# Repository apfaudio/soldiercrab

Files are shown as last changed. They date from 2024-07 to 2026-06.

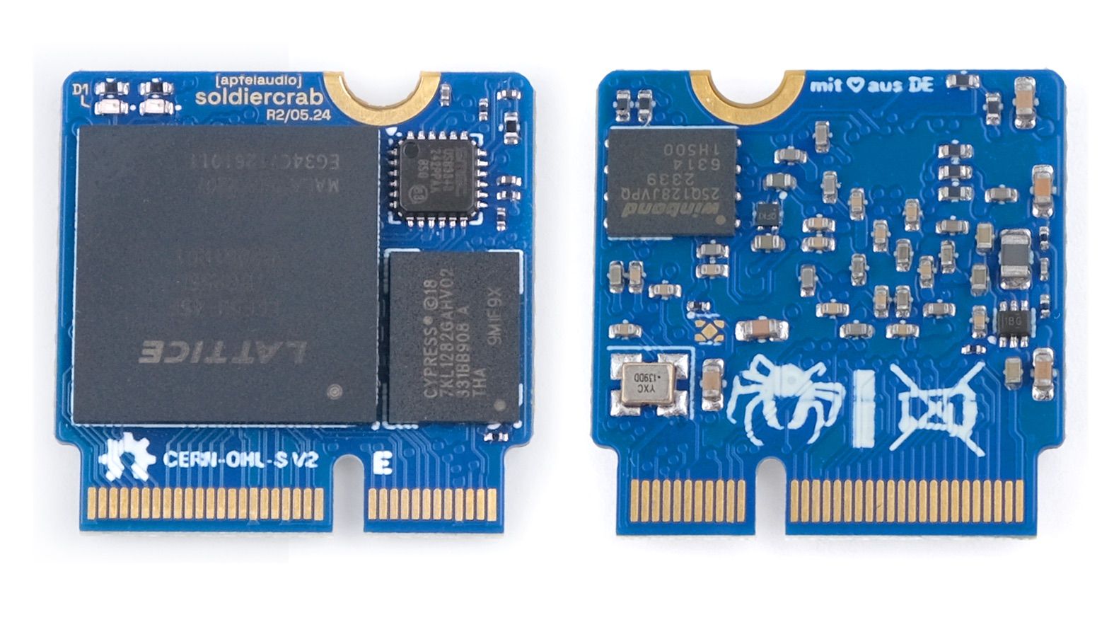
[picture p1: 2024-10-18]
img/soldiercrab-r2.jpg

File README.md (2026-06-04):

# SoldierCrab

[**SoldierCrab**](https://en.wikipedia.org/wiki/Mictyris_longicarpus) is an embeddable FPGA SoM (System-on-Module) designed for use in high-speed audio and USB applications.
It is the brain of [tiliqua](https://github.com/apfaudio/tiliqua) and other [apf.audio products](https://apf.audio/), and looks like this:



A high-level block diagram:



**SoldierCrab** has the following core features:
- **ECP5 FPGA**: -25K or -45K variant, caBGA256 (note: SERDES/PCIe not available in this package!)
- **HyperRAM / oSPI-RAM**: tested up to 3.2Gbit/sec, or 3.8Gbit/sec with timing violations :)
- **USB2 HS PHY**: 480Mbit/sec, with exposed ID, it can be used in device or host mode
- **1V1 / 1V8 / 2V5 regulators onboard**, 3V3 is all that's needed
- **PROGRAMN internally looped back** for multibooting bitstreams / internal bootloader
- 2 indicator LEDs on the PCBA
- 48MHz master clock
- Card edge is basically: **47 exposed general purpose pins + 4-pin JTAG + USB2**
- 22mmx22mm board size with M.2 E-key card edge (see 'Physical Compatibility' below)

## Hardware Revisions

**There are currently 2 revisions of SoldierCrab in the wild.**
- **R2.0**: LFE5U-45 with 7KL1282GAHY02 (3.3V HyperRAM, tested up to 200MB/sec)
- **R3.0**: LFE5U-25 with APS256XXN-OBR (1.8V oSPI-RAM, tested up to 400MB/sec)

PDF schematics for both can be found in the `schematics-pdf` folder.

## Footprint / Physical Compatibility

**The SoldierCrab is 22mmx22mm (+/- 0.3mm) with an M.2 E-key connector and offset mounting hole**. The mounting hole is offset such that this board is physically compatible with the SparkFun MicroMod format, however we **do not claim electrical compatibility with it** (even though this SoM will work with some MicroMod boards, the JTAG and I2C connections are in the wrong place for us to claim complete compatibility - this is intentional design choice to save routing space whilst trying to remain close to some kind of SoM standard).

On my carrier boards, as a connector I am using a [TE Connectivity 2199230-4](https://www.lcsc.com/product-detail/Edgeboard-Connectors_TE-Connectivity-2199230-4_C2977809.html).

A nice resource for [designing appropriate carrier boards can be found here](https://learn.sparkfun.com/tutorials/designing-with-micromod/how-to-design-a-micromod-carrier-board). However, keep the above in mind, make sure your JTAG and I2C pinouts match the SoldierCrab ones.

## Pinout

Aside from in the schematic, you can find a (tested!) version of the SoM pinout in `amaranth-boards` format [here in the Tiliqua repository](https://github.com/apfaudio/tiliqua/blob/e4d43d70f0be8f8c47809bad94cfb414b5939a86/gateware/src/tiliqua/tiliqua_platform.py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).

#### R3.0 Complementary Pairs

These pins on the M.2 connector are best for differential outputs (e.g. DVI).

```
6 are adjacent on the same side:
[(13, 15), (20, 22), (52, 54), (58, 60), (62, 64), (68, 70)]
2 are almost adjacent (1 pin gap) on the same side:
[(55, 59), (67, 71)]
10 not adjacent (>1pin gap or different sides):
[(6, 17), (11, 19), (34, 35), (38, 41), (37, 43), (40, 47), (46, 57),, (63, 69)]
```

## Where do I get one?

Pre-assembled and tested SoldierCrabs are available on [Crowd Supply](https://www.crowdsupply.com/apfaudio/tiliqua) (ships from US) or by [emailing me](https://apf.audio/impressum/) (ships from EU).

I've also published an open-hardware [carrier board called 'sandflat'](https://github.com/apfaudio/sandflat) which is a cheaper (and less feature-rich) alternative to Tiliqua, if you're just wanting to test out SoldierCrab in your own domain.

# Bootloader

In theory, this SoM could bootload itself over the ULPI USB2 PHY, however I haven't started on this yet. This means a carrier board must expose the JTAG pins for an external programmer (check the schematic).

## Builds on the following (awesome) open-hardware projects
- The [Cynthion](https://github.com/greatscottgadgets/cynthion-hardware) project from Great Scott Gadgets.
- The [OrangeCrab](https://github.com/orangecrab-fpga/orangecrab-hardware) project from Greg Davill.
- Inspired by [Sparkfun Micromod](https://www.sparkfun.com/micromod), even though we are not 100% compatible with it.

# License

**Copyright (C) 2024 S. Holzapfel**

The files in this project are largely covered under the CERN Open-Hardware License V2 CERN-OHL-S, mirrored in the LICENSE text in this repository. This LICENSE and copyright notice do NOT apply to imported artifacts in this repository (i.e datasheets, third-party 3D models, symbols or footprints), or to dependencies released under a different (but compatible) open-source license.

# Derivative works

As an addendum to the above license: if you create or manufacture your own derivative hardware, the name `apf.audio`, the names of any `apf.audio` products and the names of the authors, are *not to be used in derivative hardware or marketing materials*, except where obligated for attribution and for retaining the above copyright notice.

For example, your adaptation of "apf.audio SoldierCrab" could be called "Sandy Modular - Clawcruncher".

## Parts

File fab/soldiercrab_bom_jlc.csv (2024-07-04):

Comment | Designator | Footprint | LCSC Part #
2.2uF | C1,C2,C3,C4,C23 | C_0603_1608Metric | C23630
1uF | C5,C19,C21,C8,C13,C16,C17,C18,C22,C79,C80,C81,C82,C83 | C_0402_1005Metric | C52923
10uF | C6,C28,C29 | C_0402_1005Metric | C105884
0.1uF | C10,C35,C31,C32,C65,C7,C9,C11,C12,C14,C15,C24,C26,C33 | C_0402_1005Metric | C1525
4.7uF | C20,C27 | C_0402_1005Metric | C326586
10pF | C25 | C_0201_0603Metric | C526922
1uF | C34,C36,C37 | C_0201_0603Metric | C87143
LED 0402 RED | D1,D2 | LED_0402_1005Metric | C965790
ECP5-BGA256 | IC1 | lattice_cabga256 | C1521614
2.2uH | L1 | L_0805_2012Metric | C216156
10k | R1 | R_0201_0603Metric | C106225
100k | R2 | R_0201_0603Metric | C106224
120k | R3 | R_0201_0603Metric | C274344
2.2k | R5 | R_0402_1005Metric | C25879
5.1k | R6,R13,R109 | R_0402_1005Metric | C25905
8.06k | R7 | R_0201_0603Metric | C516470
20K | R8 | R_0402_1005Metric | C93942
27R | R9,R10 | R_0201_0603Metric | C270320
330 | R11,R12,R14,R15 | R_0402_1005Metric | C25104
330 | R108 | R_0201_0603Metric | C274872
10k | R110 | R_0402_1005Metric | C25744
TLV62569ADRLR | U1 | SOT-563 | C398367
NCP115-2.5 | U2 | Texas_X2SON-4_1x1mm_P0.65mm | C892044
NCP115-1.8 | U4 | Texas_X2SON-4_1x1mm_P0.65mm | C603501
USB3343 | U3 | QFN-24-1EP_4x4mm_P0.5mm_EP2.6x2.6mm | C633347
W25Q128JVP | U7 | WSON-8-1EP_6x5mm_P1.27mm_EP3.4x4mm | C190862
HyperRAM | U10 | BGA-24_5x5_6.0x8.0mm | C5448342
Osc48MHz | Y1 | Crystal_SMD_3225-4Pin_3.2x2.5mm | C669070

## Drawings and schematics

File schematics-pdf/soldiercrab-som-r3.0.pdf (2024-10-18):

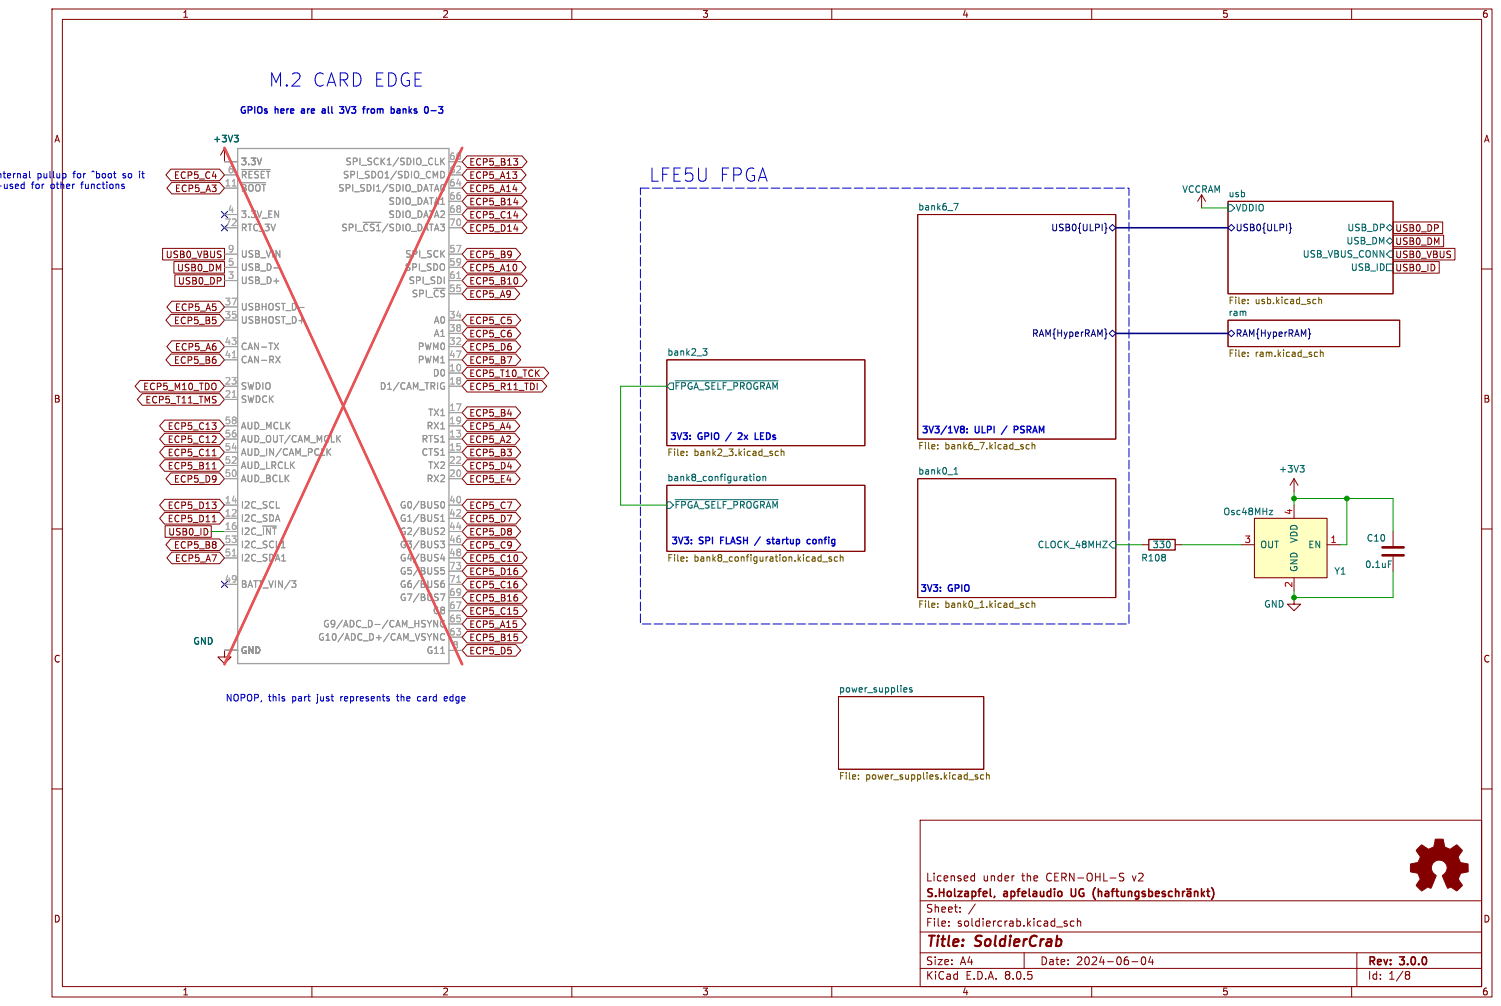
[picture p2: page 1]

3V3: GPIO / 2x LEDs GPIOs here are all 3V3 from banks 0-3 M.2 CARD EDGE

USB0{ULPI} usb File: usb.kicad_sch RAM{HyperRAM}

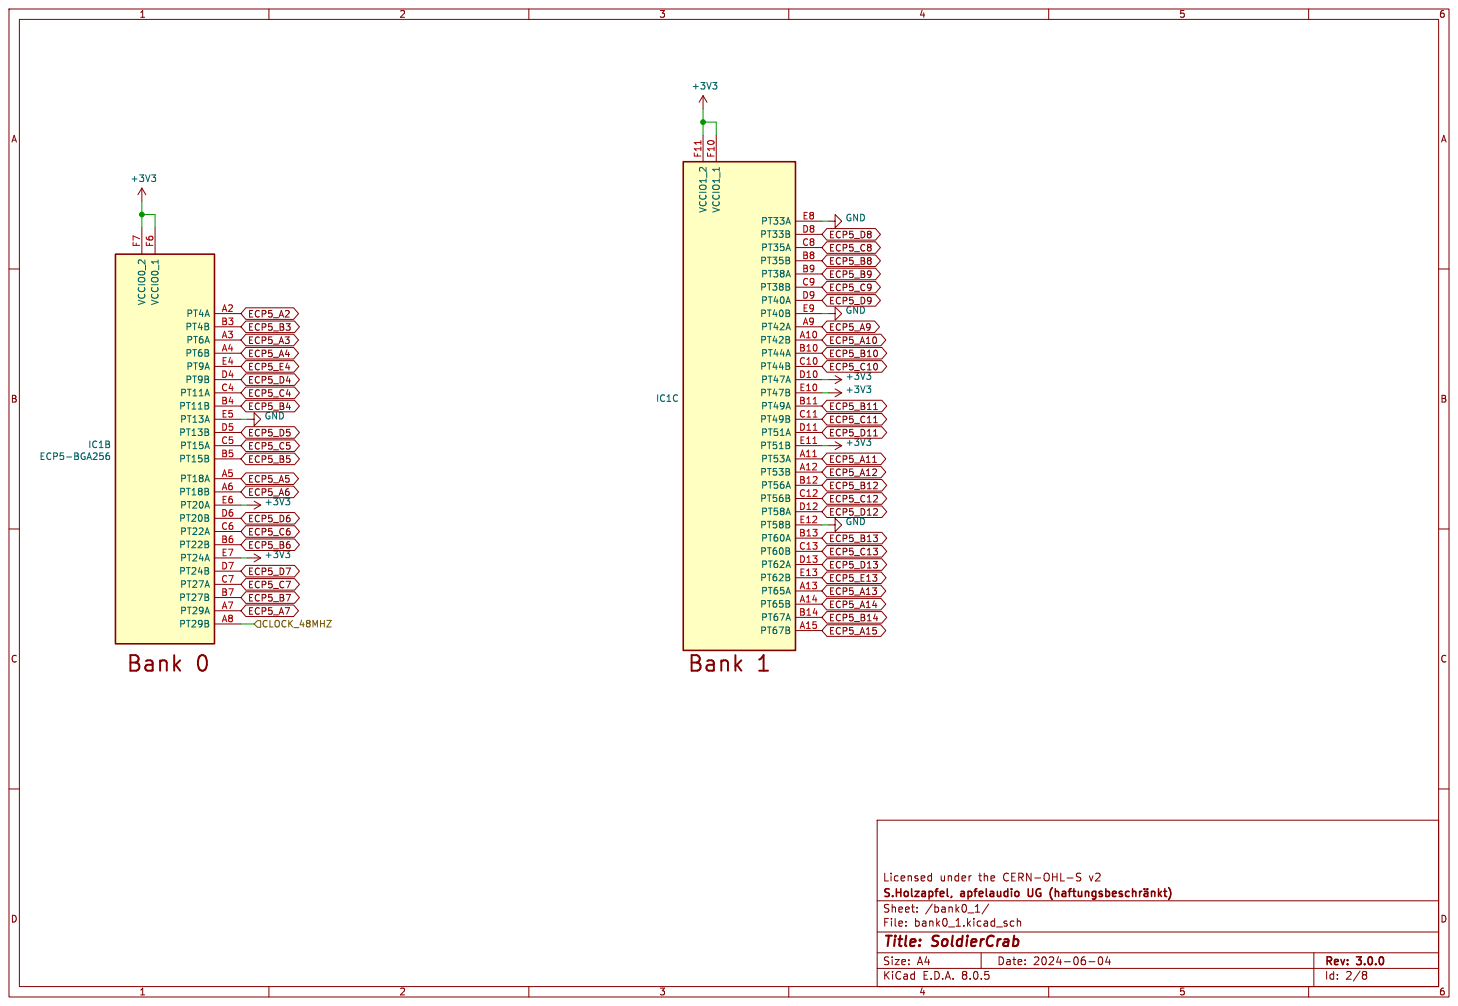
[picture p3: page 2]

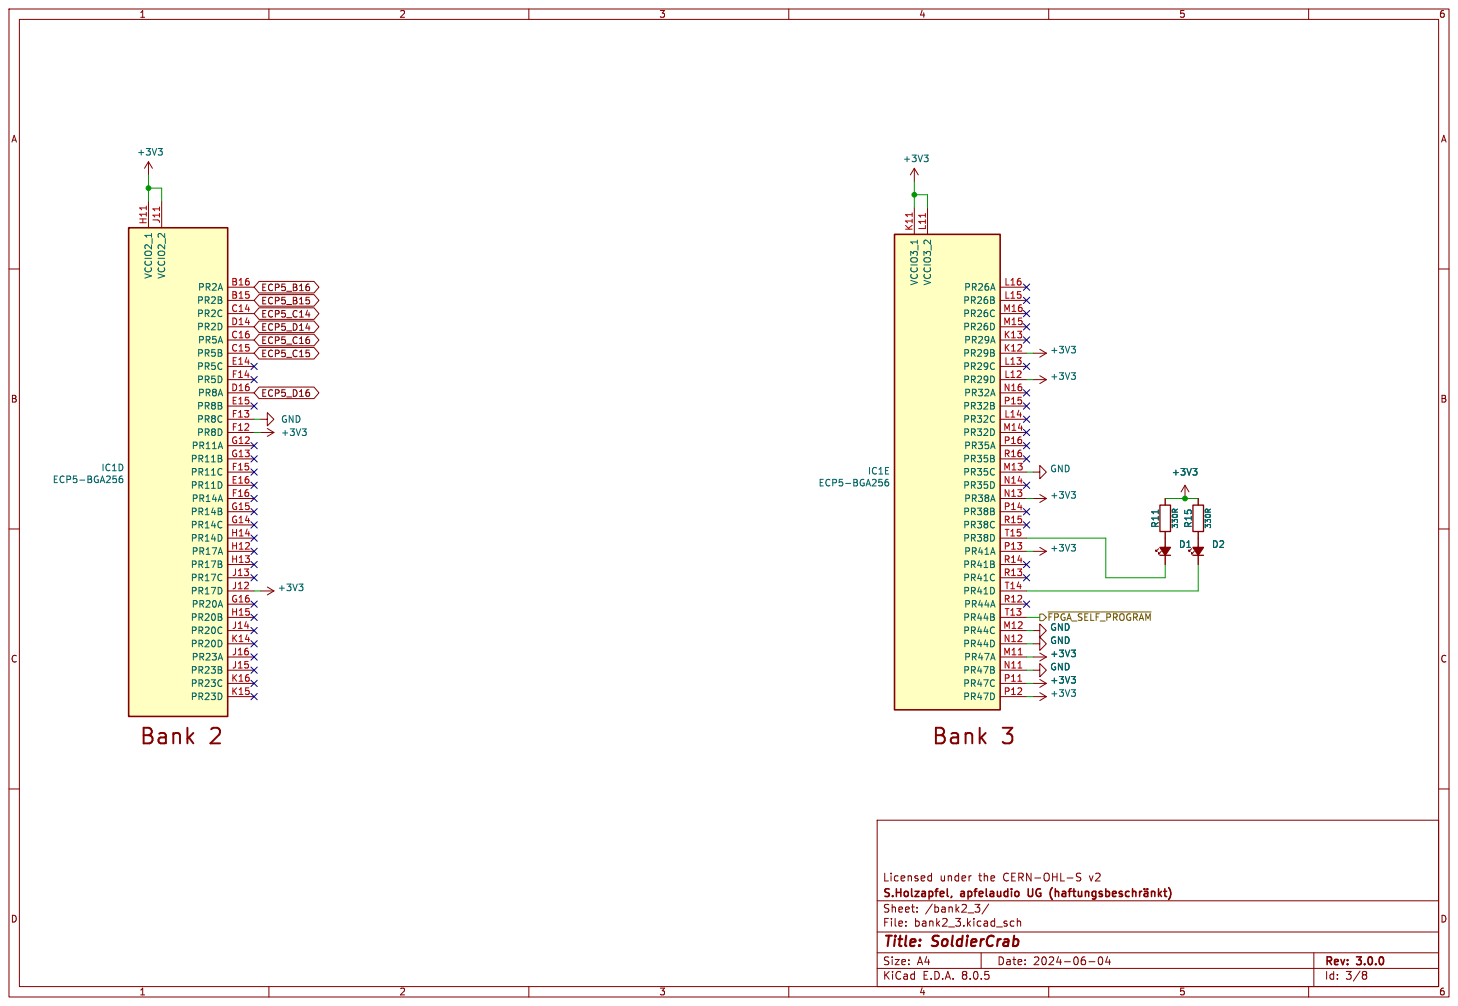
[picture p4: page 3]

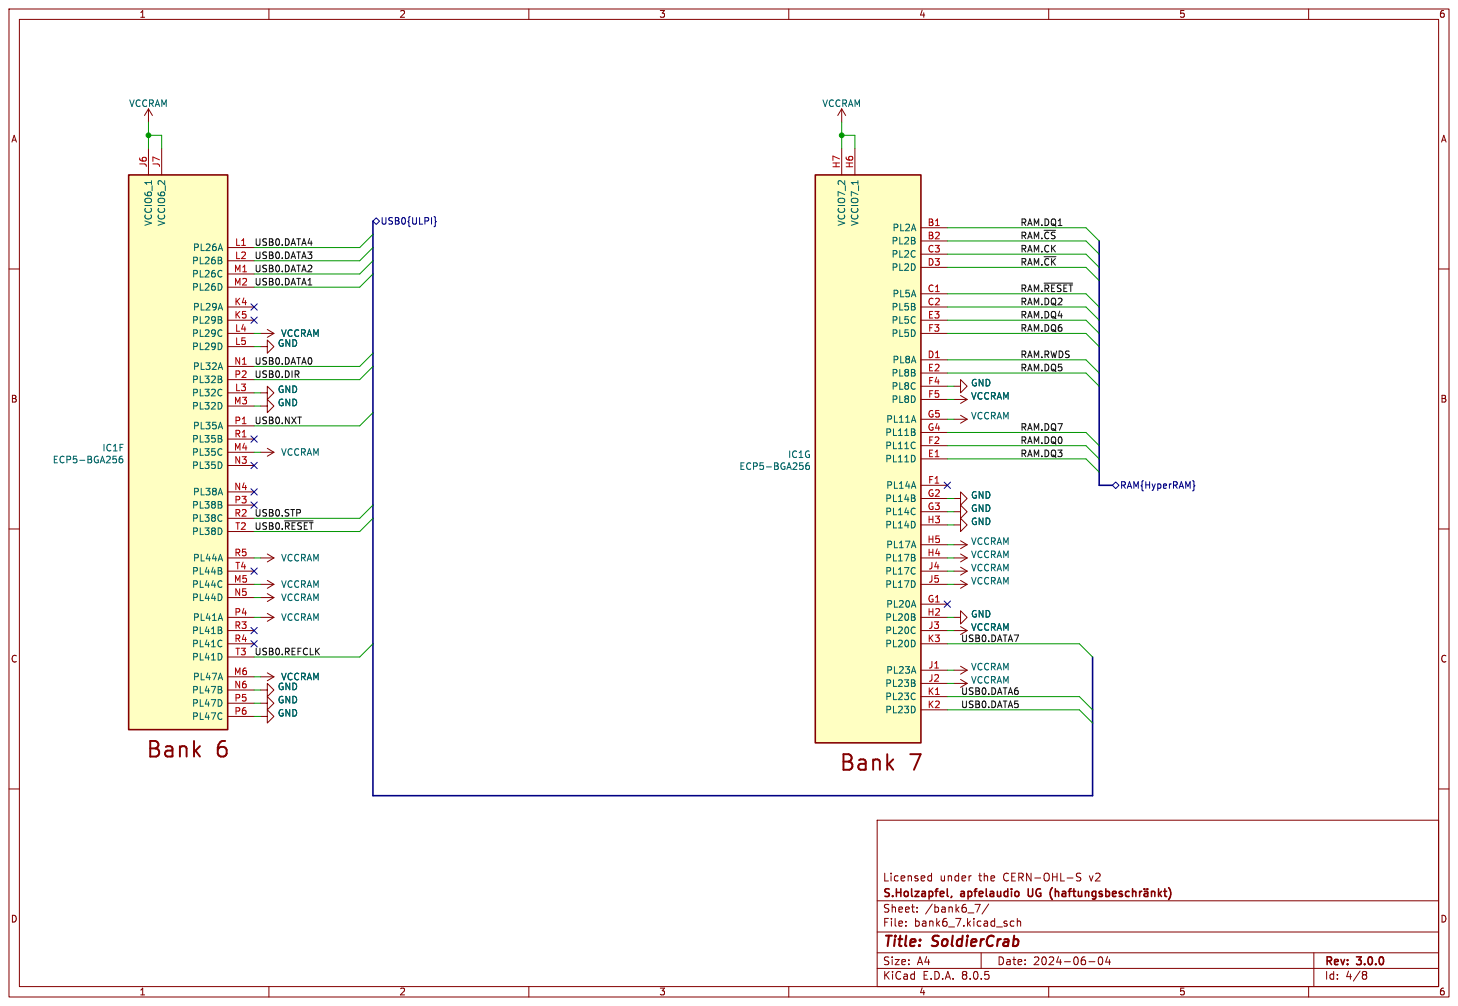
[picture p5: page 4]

RAM{HyperRAM} RAM.CK RAM.~{CK}

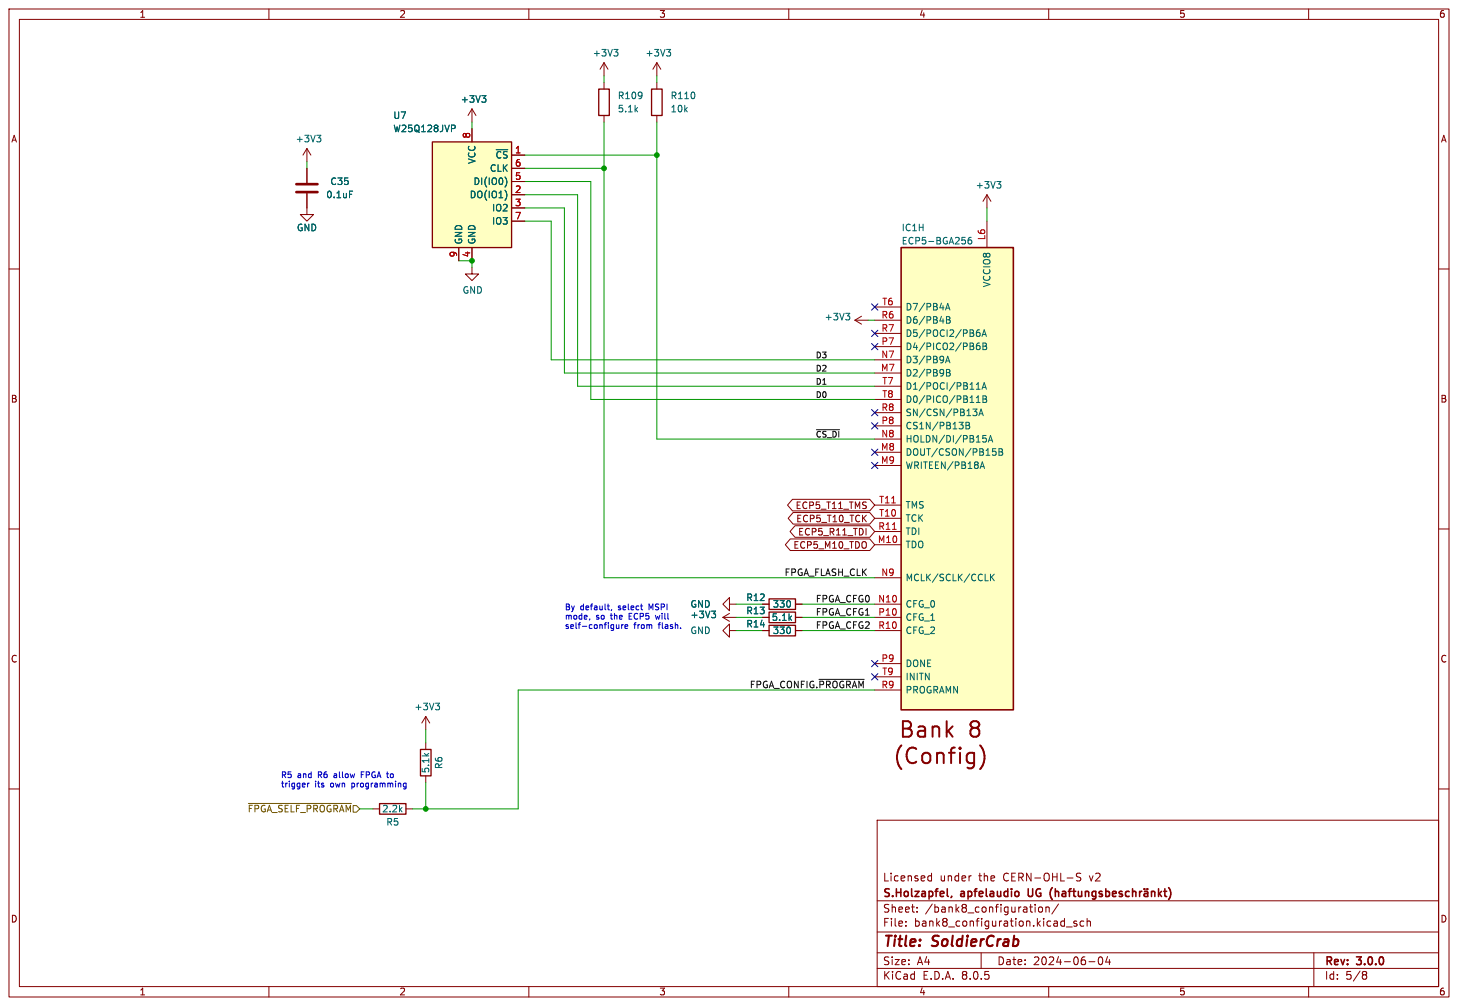
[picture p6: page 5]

~{CS_DI} D1 R5 and R6 allow FPGA to

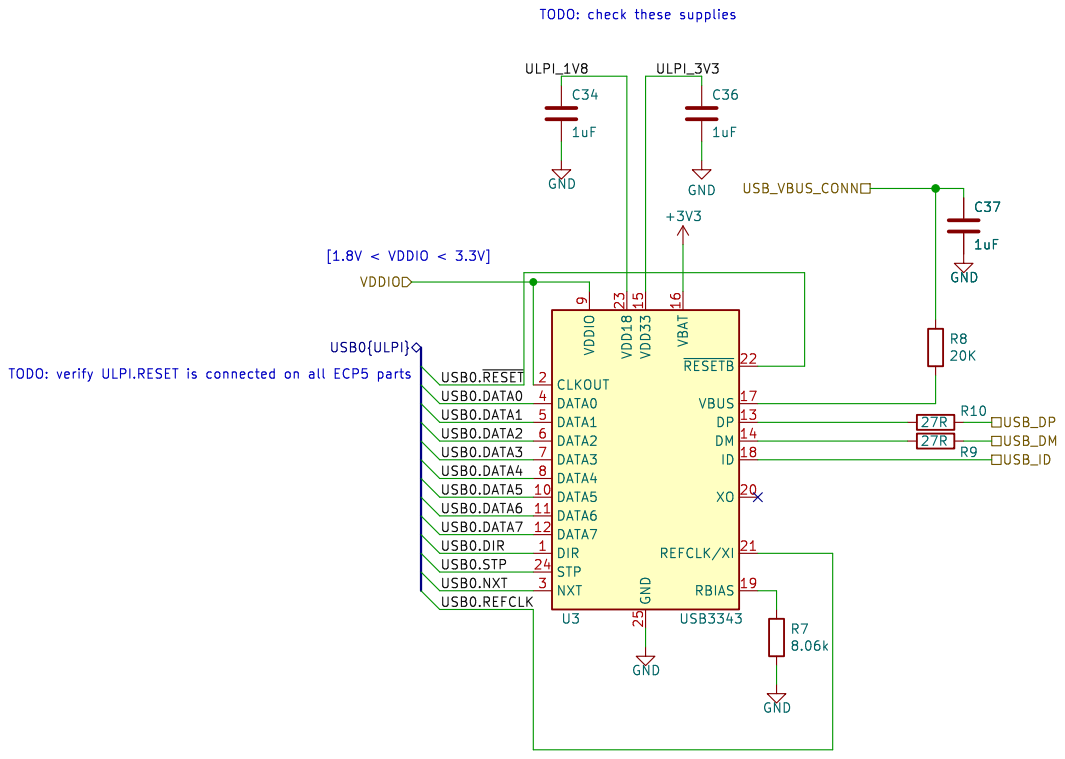
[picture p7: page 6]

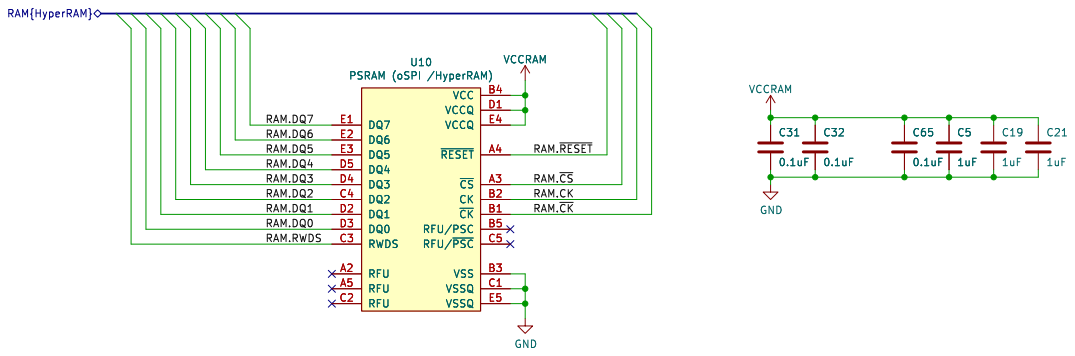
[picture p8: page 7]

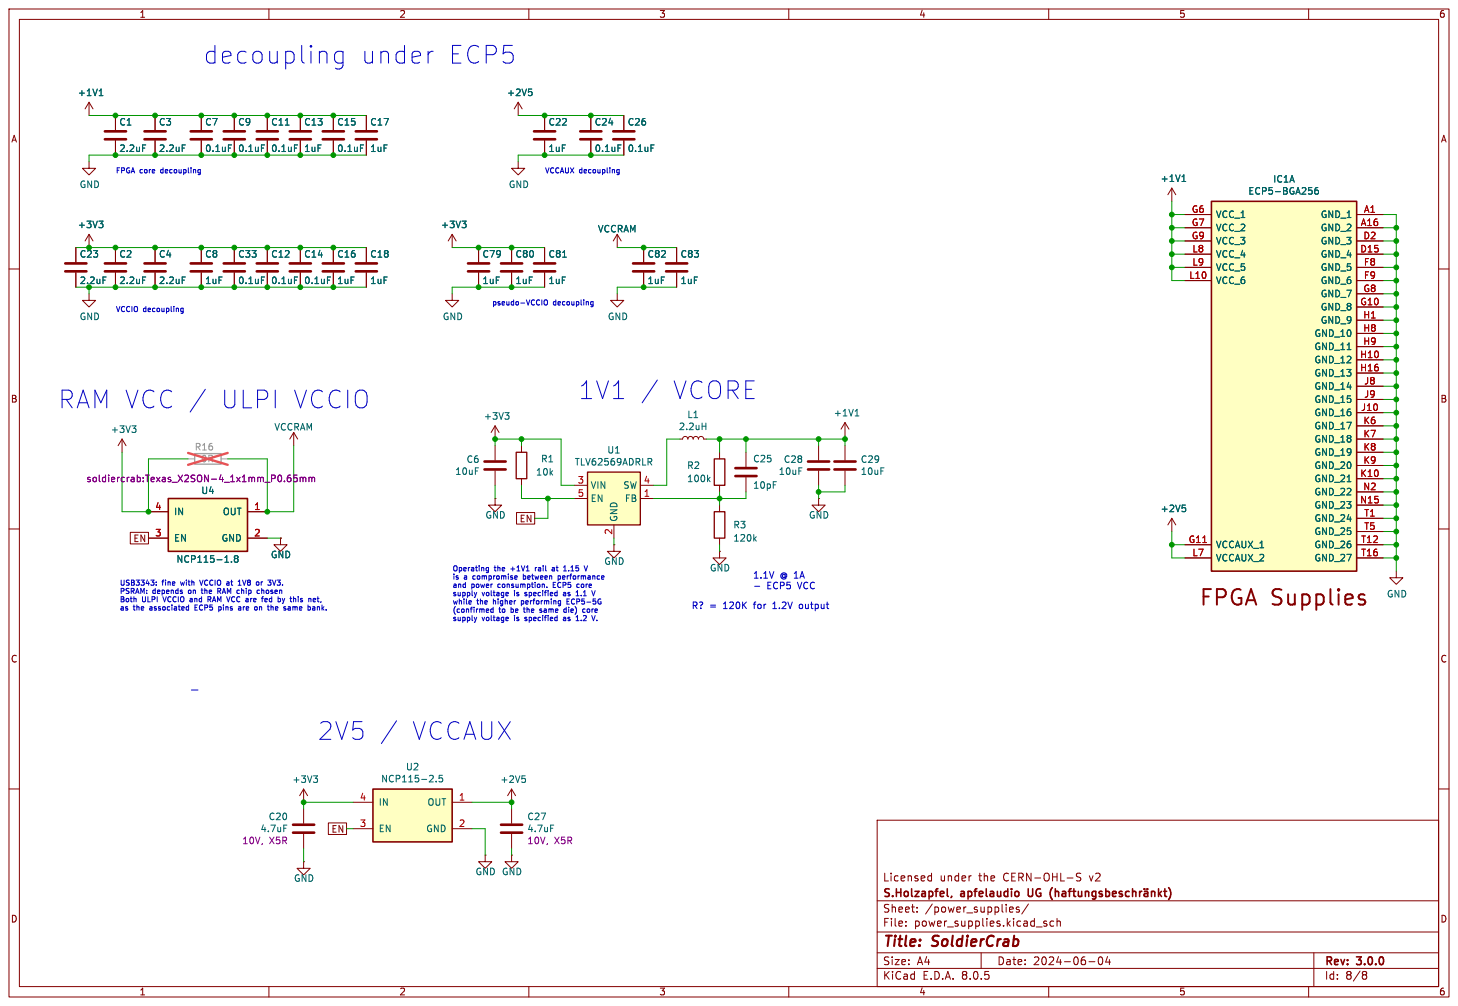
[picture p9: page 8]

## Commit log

2024-06-04 Initial copyover from internal repository
    [bank0_1.kicad_sch, bank2_3.kicad_sch, bank6_7.kicad_sch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]
2024-06-05 fab 05.06.24
    [soldiercrab_bom_jlc.csv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]
2024-06-08 increase copper -> edge clearance to 0.3mm, ground mounting hole
    [soldiercrab.kicad_pcb]
2024-07-04 r2.1: manual BOM tweaks for 25K / APmem / 1V8 - TODO update KiCAD fields!
    [soldiercrab.kicad_pcb, soldiercrab_bom_jlc.csv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]
2024-07-20 kicad: fix LED PD, APMem, 1V8, USB ~RST short
    [bank2_3.kicad_sch, power_supplies.kicad_sch, ram.kicad_sch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]
2024-07-20 update mask R3, couple GND stitches
    [soldiercrab.kicad_pcb]
2024-07-21 Move USB0_ID, connect I2C0_SCL / I2C0_SDA
    [soldiercrab.kicad_pcb, soldiercrab.kicad_sch]
2024-08-10 r3: fab
    [soldiercrab.kicad_pcb]
2024-08-11 revise clearance l/r for total X dimension 22.2mm
    [soldiercrab.kicad_pcb]
2024-10-18 README: bump for SC3 + schematics
2025-02-19 hw: keepout bottom 0.5mm, add latest part mappings
    [soldiercrab.kicad_pcb]
2025-02-19 hw: remove mask on connectors, nudge top resistor, keepout fills around connector, swap top mask circle for half-circle
    [soldiercrab.kicad_pcb]
2025-02-19 remove OHL-S, add CE/WEEE to front, update dates 2025, add UG (haftungsbeschraenkt) to back
    [soldiercrab.kicad_pcb]
